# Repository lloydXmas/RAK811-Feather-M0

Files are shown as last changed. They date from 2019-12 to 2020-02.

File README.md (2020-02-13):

# RAK811 FeatherWing for the Feather M0  

This shield gives LoRaWAN connectivity to Adafruit's Feather M0 via the RAK811 module. Examples directory demonstrate usage/configuration with The Things Network.

Advantages of using the RAK811:
* Compared to other full-stack devices, the RAK811 is small in size and fits nicely on FeatherWing dimensions.
* Using an LMIC library to run a full LoRaWAN stack on the M0 can be challenging when interrupts and delays are needed.
* By removing the LoRaWAN stack from the M0, more flash memory is available.

The M0 has 6 possible serial communication (SERCOM) interfaces. The shield has a DPDT switch to select which SERCOM is used for RAK811 communication:
* `Serial1` uses the default UART RX/TX pins at D0 and D1. 
* `Serial2` uses pins D10 and D11 for RX/TX (Examples assume Serial2 is used)

## Updating the RAK811 Module
The board has a UART breakout for updating the RAK811's firmware and bootloader as newer versions are released.
To update the bootloader with the STM32CubeProgrammer, add solder to the jumper on the bottom of PCB. Remove solder to update firmware.

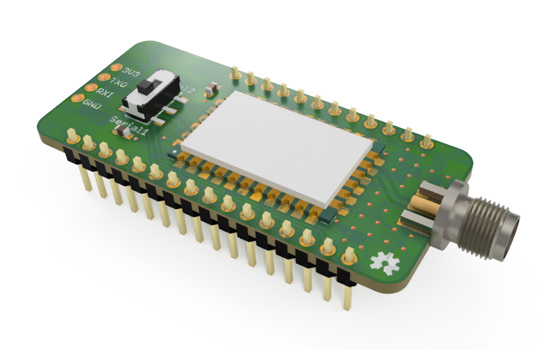
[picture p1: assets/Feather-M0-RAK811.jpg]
Feather-Shield


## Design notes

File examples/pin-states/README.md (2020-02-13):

## Encoding on the Feather

```cpp
  pinstates |= digital5;
  pinstates |= digital6 << 1;
  pinstates |= digital12 << 2;
  pinstates |= digital13 << 3;
  
  data[0] = pinstates;
  data[1] = battery;
```

## TTN Payload Decoder
The first byte in the payload holds our pin states. Bits in `pinstates` byte are masked off to retrieve corresponding values.

```javascript
function Decoder(bytes, port) {
  var decoded = {};
  
  // Mask unwanted bits in byte
  decoded.pin5 = (bytes[0] & 1) > 0 ? "HIGH" : "LOW";
  decoded.pin6 = (bytes[0] & 2) > 0 ? "HIGH" : "LOW";
  decoded.pin12 = (bytes[0] & 4) > 0 ? "HIGH" : "LOW";
  decoded.pin13 =  (bytes[0] & 8) > 0 ? "HIGH" : "LOW";
  // Battery charge
  decoded.bat = bytes[1];   

  return decoded;
}
```

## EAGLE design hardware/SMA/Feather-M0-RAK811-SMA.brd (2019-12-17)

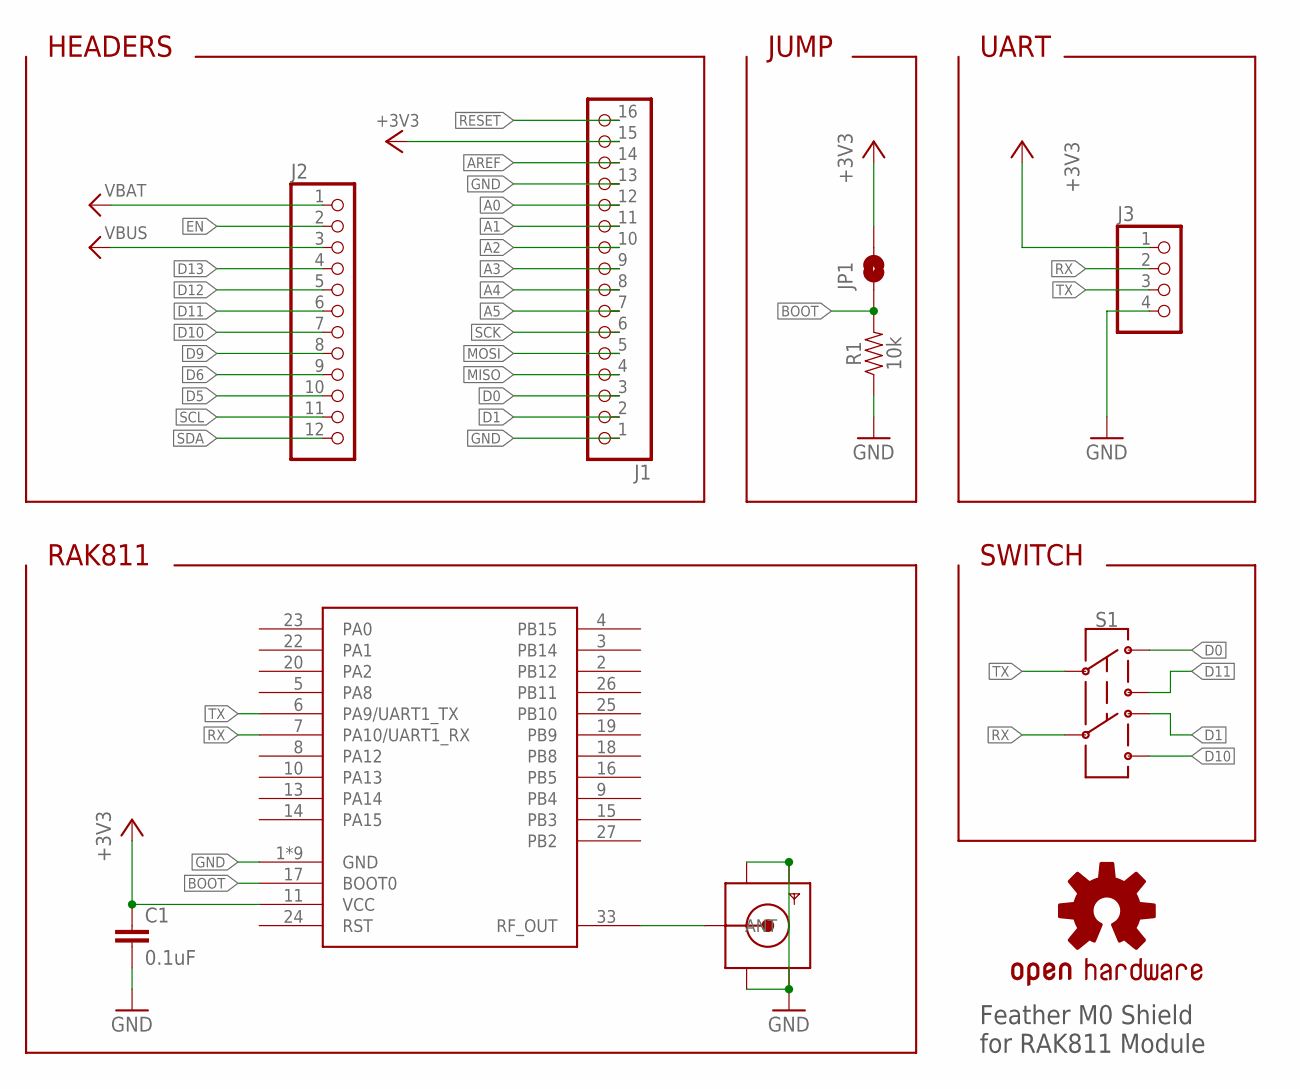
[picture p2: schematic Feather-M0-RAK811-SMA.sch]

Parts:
C1: 0.1uF; 0603
J1: HEADER-1X16ROUND; 1X16_ROUND
J2: HEADER-1X12; 1X12_ROUND
J3: HEADER-1X4ROUND; 1X04_ROUND
JP1: JUMPER-SMT_2_NO_SILK; SMT-JUMPER_2_NO_SILK
LOGO1: OSHW-LOGOS; OSHW-LOGO-S
R1: 10k; 0603
S1: SWITCH-DPDT-SMD-AYZ0202; SWITCH_DPDT_SMD_AYZ0202
U1: RAK_WIRELESS_RAK811
X1: SMACONNECTOR_EDGE; SMA_EDGELAUNCH

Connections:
!RESET: J1.16
+3V3: C1.1, J1.15, J3.1, JP1.2, U1.11 (VCC)
A0: J1.12
A1: J1.11
A2: J1.10
A3: J1.9
A4: J1.8
A5: J1.7
AREF: J1.14
BOOT: JP1.1, R1.2, U1.17 (BOOT0)
D0: J1.3, S1.1
D1: J1.2, S1.4
D5: J2.10
D6: J2.9
D9: J2.8
D10: J2.7, S1.6
D11: J2.6, S1.3
D12: J2.5
D13: J2.4
EN: J2.2
GND: C1.2, J1.1, J1.13, J3.4, R1.1, U1.1 (GND), U1.12 (GND), U1.21 (GND), U1.28 (GND), U1.29 (GND), U1.30 (GND), U1.31 (GND), U1.32 (GND), U1.34 (GND), X1.GND@1 (GND4), X1.GND@2 (GND3), X1.GND@3 (GND2), X1.GND@4 (GND1)
MISO: J1.4
MOSI: J1.5
RF: U1.33 (RF_OUT), X1.P (ANT)
RX: J3.2, S1.5, U1.7 (PA10/UART1_RX)
SCK: J1.6
SCL: J2.11
SDA: J2.12
TX: J3.3, S1.2, U1.6 (PA9/UART1_TX)
VBAT: J2.1
VBUS: J2.3

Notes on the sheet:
UART
HEADERS
JUMP
RAK811
Feather M0 Shield for RAK811 Module
SWITCH

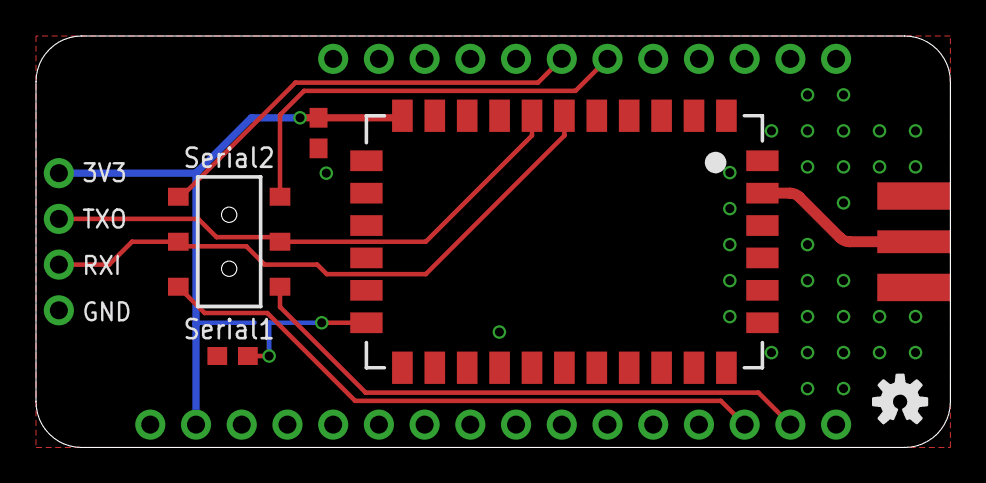
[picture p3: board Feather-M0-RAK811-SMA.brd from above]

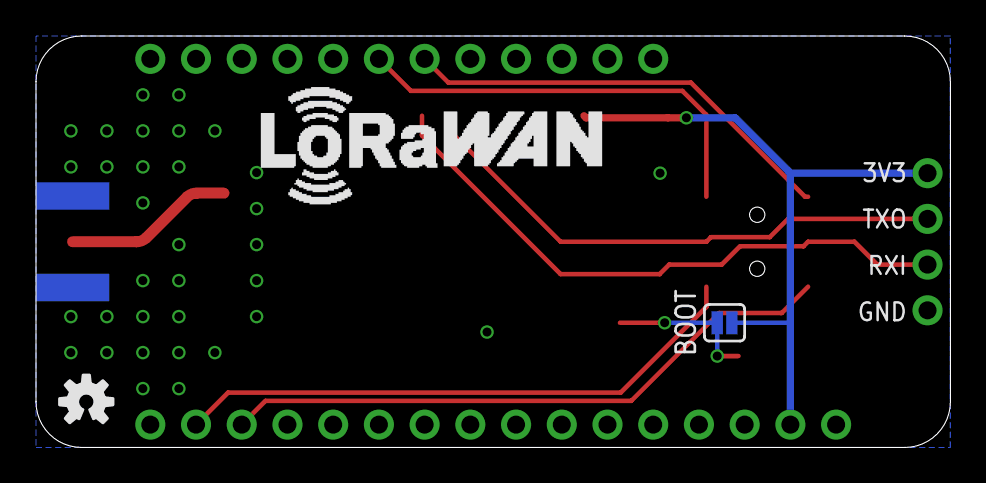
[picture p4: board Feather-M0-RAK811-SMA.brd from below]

Board: 2 copper layers, 50.8 x 22.9 mm, 12 parts (3 on the bottom side), 10 nets.

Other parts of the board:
LOGO2: OSHW-LOGOS; OSHW-LOGO-S
U$1: LORAWAN

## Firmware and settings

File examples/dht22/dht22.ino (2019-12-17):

/*
DHT22 sensor is connected to pin 5 of the Feather.

formatFloat() rounds temperature and humidity values to nearest
hundreth & multiplies by 100 to fit nicely into buffer.
Notem that temperature is a signed integer as it may be negative.

Sketch assumes Serial2 on D10/D11 is being used. Comment-out
SERCOM1 lines and use Serial1 if using defualt UART pins.
*/
#include <Arduino.h>
#include <DHT.h>
#include <wiring_private.h>

// DHT definition & instance
#define DHTPIN 5
#define DHTTYPE DHT22
DHT dht(DHTPIN, DHTTYPE);

// Create Serial2 from SERCOM pins 11 & 10
Uart Serial2(&sercom1, 11, 10, SERCOM_RX_PAD_0, UART_TX_PAD_2);
void SERCOM1_Handler() { Serial2.IrqHandler(); }

void setup() {
  Serial.begin(115200);   // USB Serial line
  Serial2.begin(115200);  // LoRa Serial line

  dht.begin();

  // Assign pins 10 & 11 SERCOM functionality
  pinPeripheral(10, PIO_SERCOM);
  pinPeripheral(11, PIO_SERCOM);
}

void loop() {
  float temp = dht.readTemperature();
  float hum = dht.readHumidity();

  Serial.print(F("Humidity: "));
  Serial.println(hum);
  Serial.print(F("Temperature: "));
  Serial.println(temp);

  // Format floats for packet
  int16_t t = formatFloat(temp);
  uint16_t h = formatFloat(hum);

  // Create packet with dht data
  uint8_t data[3];
  data[0] = highByte(t);
  data[1] = lowByte(t);
  data[2] = highByte(h);
  data[3] = lowByte(h);

  // Send packet
  sendPayload(data, sizeof(data));

  delay(15000);
}

// Returns a float rounded to nearest 100th & multiplied by 100
float formatFloat(float input) {
  input = roundf(input * 10) / 10;
  input = round(input * 100);
  return input;
}

// Formats payload to hex & sends it
void sendPayload(uint8_t* payload, size_t length) {
  uint8_t i = 0;
  Serial2.print("at+send=lora:2:");
  Serial.print(F("Payload: "));
  for (i = 0; i < length; i++) {
    if (payload[i] < 16) {
      Serial2.print("0");
      Serial2.print(payload[i], HEX);
      Serial.print(F("0"));
      Serial.print(payload[i], HEX);
    } else {
      Serial2.print(payload[i], HEX);
      Serial.print(payload[i], HEX);
    }
  }
  Serial.println("");
  Serial2.write("\r\n");
  delay(10);
}

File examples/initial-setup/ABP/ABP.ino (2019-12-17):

// Initial setup for ABP mode of RAK811 module.

#include <Arduino.h>
#include <wiring_private.h>

// Create Serial2 from SERCOM pins 11 & 10
Uart Serial2(&sercom1, 11, 10, SERCOM_RX_PAD_0, UART_TX_PAD_2);
void SERCOM1_Handler() { Serial2.IrqHandler(); }

// Region: EU868, US915
String region = "US915";

// ABP Parameters: Device Address, Network Session Key, App Session Key
String devAddr = "00000000";
String nwksKey = "00000000000000000000000000000000";
String appsKey = "00000000000000000000000000000000";

void setup() {
  Serial.begin(115200);   // USB Serial line
  Serial2.begin(115200);  // LoRa Serial line

  // Assign pins 10 & 11 SERCOM functionality
  pinPeripheral(10, PIO_SERCOM);
  pinPeripheral(11, PIO_SERCOM);
}

void loop() {
  if (Serial) {
    // Set region
    Serial.println(F("Setting Region"));
    setConfig("region", region);
    delay(1000);

    // Set Join Mode to ABP
    Serial.println(F("Setting Join-Mode to ABP"));
    setConfig("join_mode", "1");
    delay(1000);

    // Set as Class A device
    Serial.println(F("Setting Device Type to Class A"));
    setConfig("class", "0");
    delay(1000);

    // ABP parameters
    Serial.println(F("Hardcoding Device Address"));
    setConfig("dev_addr", devAddr);
    delay(500);
    Serial.println(F("Hardcoding NwkSKey"));
    setConfig("nwks_key", nwksKey);
    delay(500);
    Serial.println(F("Hardcoding AppSKey"));
    setConfig("apps_key", appsKey);
    delay(500);

    sendCmd("at+join");
    delay(1000);
    Serial.println(F("Setup complete!"));
    Serial.println(F("If you see any ERROR messages, check your keys"));
    while (1) {
      delay(1);
    }
  }
}

void sendCmd(String cmd) {
  String reply;
  Serial2.print(cmd);
  Serial2.write("\r\n");
  while (Serial2.available()) {
    char c = Serial2.read();
    reply += c;
  }
  Serial.println(reply);
  delay(500);
}

void setConfig(String key, String value) {
  sendCmd("at+set_config=lora:" + key + ":" + value);
}

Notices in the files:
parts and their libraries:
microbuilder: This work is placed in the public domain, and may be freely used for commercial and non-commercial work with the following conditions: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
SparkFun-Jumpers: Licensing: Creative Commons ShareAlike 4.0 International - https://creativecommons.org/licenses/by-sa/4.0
